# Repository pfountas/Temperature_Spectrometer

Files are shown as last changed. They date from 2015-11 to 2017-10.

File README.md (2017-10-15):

# Temperature Spectrometer
Temperature Spectrometer based on the NXP mbed LPC1768 platform.

This is an embedded digital temperature spectrometer with logging capabilities. The system was based on the NXP mbed LPC1768 platform. The microcontroller used in the temperature logger is based on the 32-bit ARM Cortex-M3 microcontroller with 512 kB flash and 64 kB SRAM. The microcontroller was connected to a TMP102 temperature sensor using an I2C interface and to an LCD screen using an SPI interface. The system supports real-time temperature spectrum computation and control and data export through an on-board USB UART connection.

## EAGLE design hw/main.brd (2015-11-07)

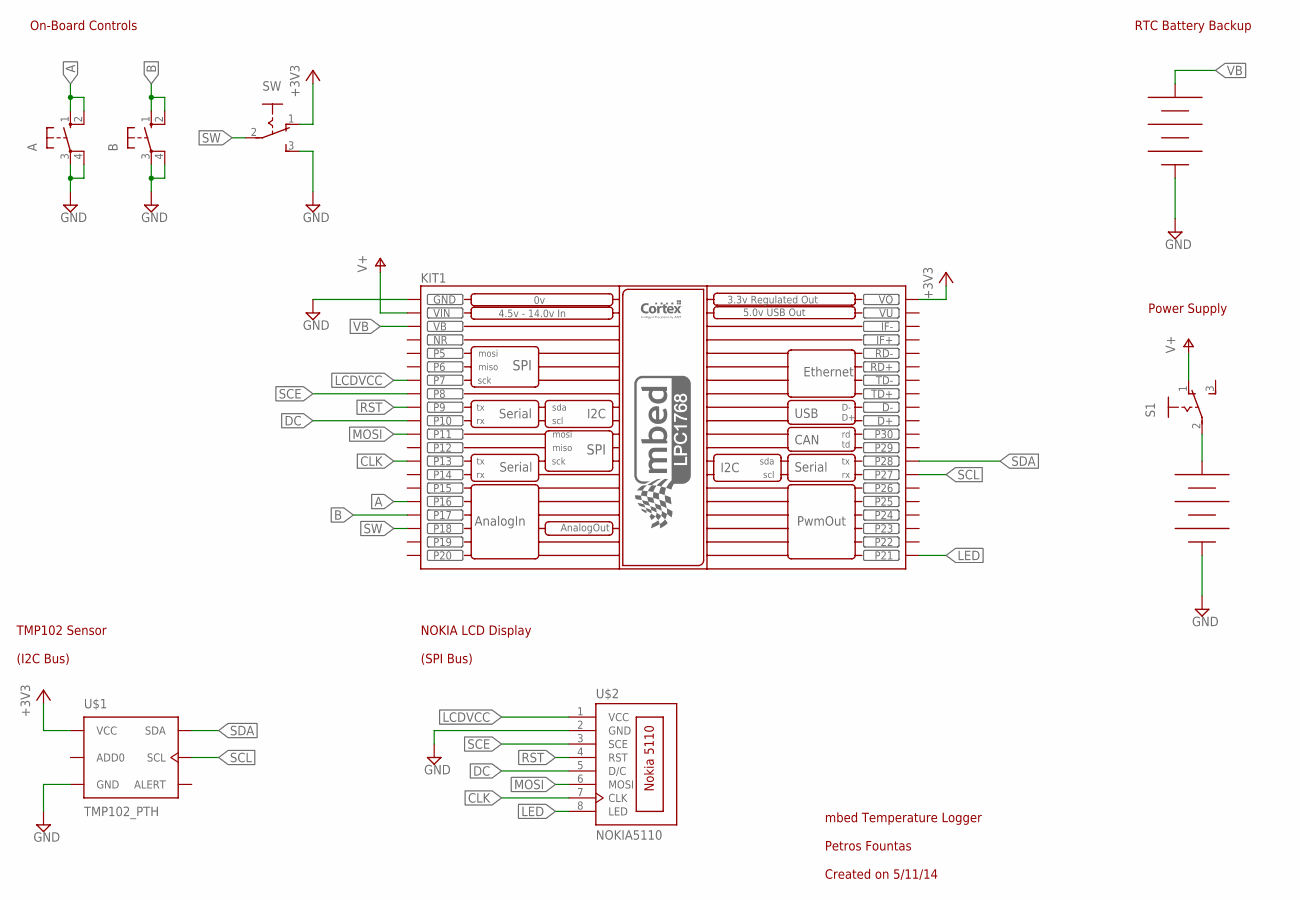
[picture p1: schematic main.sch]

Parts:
A: BUTTON_THT; BUTTON
B: BUTTON_THT; BUTTON
BATT1: BATTERY_4AA
BATT2: BATTERY_H_CR2032; BATTERY_H
KIT1: MBED_SILK; MBED
S1: M251
SW: M251
U$1: TMP102_PTH; TMP102
U$2: NOKIA5110

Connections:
+3V3: KIT1.VOUT (VO), SW.1 (O), U$1.VCC
A: A.1 (S), A.2 (S1), KIT1.P$16 (P16)
B: B.1 (S), B.2 (S1), KIT1.P$17 (P17)
CLK: KIT1.P$13 (P13), U$2.7 (CLK)
DC: KIT1.P$10 (P10), U$2.5 (D/C)
GND: A.3, A.4 (P1), B.3, B.4 (P1), BATT1.-, BATT2.-, KIT1.GND, SW.3 (S), U$1.GND, U$2.2 (GND)
LCDVCC: KIT1.P$7 (P7), U$2.1 (VCC)
LED: KIT1.P$21 (P21), U$2.8 (LED)
MOSI: KIT1.P$11 (P11), U$2.6 (MOSI)
unnamed: BATT1.+, S1.2
NR: KIT1.NR
RST: KIT1.P$9 (P9), U$2.4 (RST)
SCE: KIT1.P$8 (P8), U$2.3 (SCE)
SCL: KIT1.P$27 (P27), U$1.SCL
SDA: KIT1.P$28 (P28), U$1.SDA
SW: KIT1.P$18 (P18), SW.2
V+: KIT1.VIN, S1.1 (O)
VB: BATT2.+, KIT1.VB
VU: KIT1.VU

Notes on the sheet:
mbed Temperature Logger Petros Fountas Created on 5/11/14
RTC Battery Backup
Power Supply
TMP102 Sensor (I2C Bus)
NOKIA LCD Display (SPI Bus)
On-Board Controls

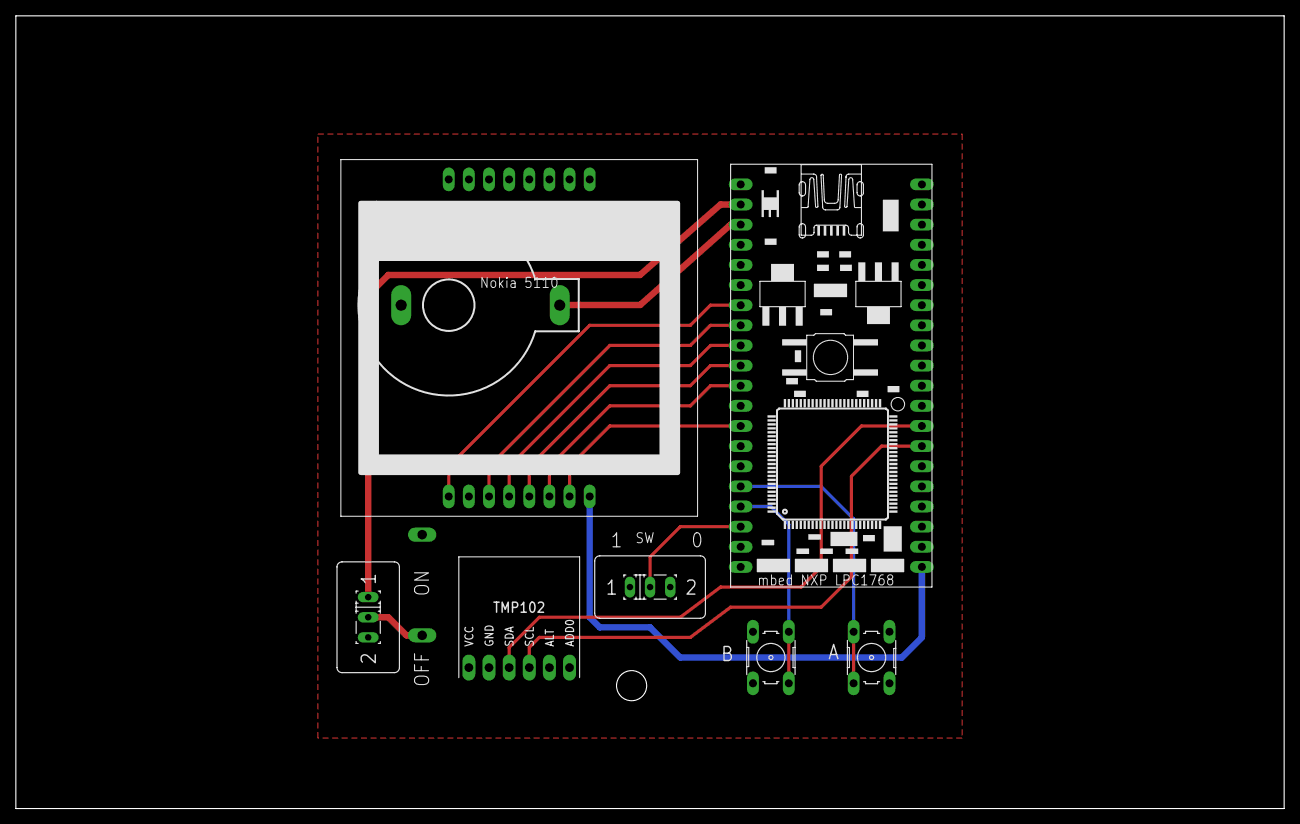
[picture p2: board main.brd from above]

Board: 2 copper layers, 160.0 x 100.0 mm, 9 parts (1 on the bottom side), 17 nets.

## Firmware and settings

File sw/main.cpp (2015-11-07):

#include "mbed.h"
#include "rtos.h"
#include "N5110.h"
#include "TMP102.h"
#include "dsp.h"

// On-boards LEDs for visual feedback
BusOut leds(LED4, LED3, LED2, LED1);

// Local filesystem
LocalFileSystem local("local");
FILE *fp = NULL;

// On-board controls
DigitalIn a_btn(p16, PullUp);
DigitalIn b_btn(p17, PullUp);
DigitalIn sw(p18);

// Serial connection
Serial serial(USBTX, USBRX);
#define getc(c) 	serial.getc(c)
#define printf(...) serial.printf( __VA_ARGS__ )

// Temperature sensor
TMP102 tmp(0x48, p28, p27); // I2C Temperature sensor
bool enable = 0;
bool isLoggingOn = 0;

// LCD display
N5110 display(p7, p8, p9, p10, p11, p13, p21); // LCD 84x48
#define DISP_WIDTH 	84
#define DISP_HEIGHT 48
bool dirty; // screen redraw flag

// DFT
#define N  64 	// samples
#define Fs 1000 // Sampling frequency
float x[N];        // signal
complex_t cx[N];   // complex signal
complex_t X[N];    // DFT
float spectrum[N]; // Spectrum
float Pxx[N];      // PSD

// Control state machine
int state, pstate;
#define DISP_SIG 1
#define DISP_DFT 2
#define DISP_PSD 3

// function to plot line on display
void plotLine(N5110 *display, float points[], int npoints) {

	// find max(point) and min(point)
	float max, min;
	min = max = 0;
	for (int n = 0; n < npoints; n++) {
		max = (points[n] > max) ? points[n] : max;
		min = (points[n] < min) ? points[n] : min;
	}

	// Y-axes
	float zero_point = (0-min)/(max-min); // normalise to [0..1]
	float zero_h = (DISP_HEIGHT-1) - int(zero_point*(DISP_HEIGHT-1)); // px
	display->setPixel(0,zero_h); // set pixel
	display->setPixel(1,zero_h); // set pixel
	for (int h = 0; h < DISP_HEIGHT; h++) {
		display->setPixel(2,h); // set pixel
	}

	// normalise points to screent height
	for (int n = 0; n < npoints; n++) {
		float norm_point = (points[n]-min)/(max-min); // normalise to [0..1]
		float h = (DISP_HEIGHT-1) - int(norm_point*(DISP_HEIGHT-1)); // px
		display->setPixel(n+3,h); // set pixel
	}

	// refresh display
    display->refresh();
}

// Compute DFT
void computeDFT() {

	// convert signal to complex
	for (int n = 0; n < N; n++) cx[n] = complex_num(x[n], 0);

	// init DFT output sequence
	for (int n = 0; n < N; n++) X[n] = complex_num(0, 0); // init to 0

	// compute DFT
	dft(X, cx, N);

	// remove DC component and AC alliases, and spread the rest of the signal
	for (int n = 0; n < N; n++)
		spectrum[n] = 0;
	for (int n = 0; n < floor(N / 2) - 1; n++) {
		spectrum[2 * n] = complex_norm(X[n + 1]);
		spectrum[2 * n + 1] =
				(complex_norm(X[n + 2]) + complex_norm(X[n + 1])) / 2;
	}
}

// Compute PSD
void computePSD() {

	// estimate Power Spectral Density (PSD)
	for (int n = 0; n < N; n++) Pxx[n] = 0; // init to 0
	for (int n = 0; n < floor(N / 2) - 1; n++) {
		Pxx[2 * n] = 20 * log10(pow(complex_norm(X[n + 1]), 2));
		float avg = (complex_norm(X[n + 2]) + complex_norm(X[n + 1])) / 2;
		Pxx[2 * n + 1] = 20 * log10(pow(avg, 2));
	}
}

union sample_union {
	float f;
	unsigned char b[4];
} sample;

// Serial DAQ
void matlab_rx() {

	// get data from Matlab
	for (int n = 0; n < N; n++) {
		x[n] = 0;

		// read number octet by octet
		sample.b[0] = (unsigned char) getc(); // b0
		sample.b[1] = (unsigned char) getc(); // b1
		sample.b[2] = (unsigned char) getc(); // b2
		sample.b[3] = (unsigned char) getc(); // b3

		// save sample
		x[n] = sample.f;
	}

	// DFT
	computeDFT();

	// Periodogram
	computePSD();

	// flag screen to be redraw
	dirty = 1;
}

// Temperature Data-Acquisition thread
void tmp_daq(void const *args) {

	char buffer[30];

	while (1) {
		float avg = 0;

		if (isLoggingOn) {
			// if the file doesn't exist it is created, if it exists, data is appended to the end
			leds = 0xf; // turn on LEDs for feedback
			fp = fopen("/local/log.csv", "a"); // open 'log.csv' for appending
		} else {
			fclose(fp); // close file
			leds = 0x0; // turn off LEDs to signify file access has finished
		}

		// acquire enough samples for the DFT
		for (int n = 0; n < N; n++) {
			float temp = 0;
			// get temperature
			tmp.temp(&temp);
			avg += (x[n] = temp);

			// format time into a string (time and date)
			time_t seconds = time(NULL); // get current time
			strftime(buffer, 30, "%X %D", localtime(&seconds));
			if (isLoggingOn && fp != NULL) {
				// write to local filesystem
				fprintf(fp, "%s, %.2f\n", buffer, temp);
			}

			// 8Hz daq rate (maximum)
			Thread::wait(0.125);

			//wait(60);
		}
		avg /= N;
		// write to serial
		//printf("%s, %.2f\n", buffer, temp);

		// display average temperature
		//char buffer[6] = "";
		//sscanf(buffer,"%f",&avg);
		//display.printString(buffer,65,0);

		// DFT
		computeDFT();

		// Periodogram
		computePSD();

		// flag screen to be redraw
		dirty = 1;
	}
}

// main
int main() {

	set_time(1420753443); // initialise time to 1st January 1970

	// init temperature sensor
	enable = 0;
	tmp.init(1);

	// init LCD display
	dirty = 0;
	display.init();

	// temperature daq thread
	Thread thread(tmp_daq);

	// matlab rx callback
	serial.attach(&matlab_rx);

	// Controller
	pstate = 0,state = DISP_SIG; // init control state machine
	while(1) {

		// Controls
		if (sw) { // SW = 1 - Signal Analysis ...
			if (!a_btn) // Button A - Spectrum display
				state = DISP_DFT;
			if (!b_btn) // Button B - Power Spectral Density display
				state = DISP_PSD;
		} else { // SW = 0 - Temperature display, Logging control ...
			state = DISP_SIG;
			if (!a_btn)  // Button A - Switch logging On (default is Off)
				isLoggingOn = 1;
			if (!b_btn) // Button B - Switch logging Off
				isLoggingOn = 0;
		}

		// State decoder
		char phrase[13];
		if (dirty || pstate != state) {
			display.clear(); // clear display

			switch (state) {
			case DISP_SIG:
				sprintf(phrase,"Temp: %.2f C",x[0]);
				display.printString(phrase,0,0); // print temperature
				break;
			case DISP_DFT:
				plotLine(&display,spectrum,N); // Display Spectrum
				break;
			case DISP_PSD:
				plotLine(&display,Pxx,N); // Display Periodogram
				break;
			default:
				sprintf(phrase,"Temp: %.2f C",x[0]);
				display.printString(phrase,0,0); // print temperature
				break;
			}
			dirty = 0;
			pstate = state;
		}

	}

}

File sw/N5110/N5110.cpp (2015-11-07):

/**
@file N5110.cpp

@brief Member functions implementations

*/
#include "mbed.h"
#include "N5110.h"


N5110::N5110(PinName pwrPin, PinName scePin, PinName rstPin, PinName dcPin, PinName mosiPin, PinName sclkPin, PinName ledPin)
{
    
    spi = new SPI(mosiPin,NC,sclkPin); // create new SPI instance and initialise
    initSPI();    
    
    // set up pins as required
    led = new PwmOut(ledPin);
    pwr = new DigitalOut(pwrPin);
    sce = new DigitalOut(scePin);
    rst = new DigitalOut(rstPin);
    dc = new DigitalOut(dcPin);

}

// initialise function - powers up and sends the initialisation commands
void N5110::init()
{
    turnOn();     // power up
    wait_ms(10);  // small delay seems to prevent spurious pixels during mbed reset
    reset();      // reset LCD - must be done within 100 ms

    // function set - extended
    sendCommand(0x20 | CMD_FS_ACTIVE_MODE | CMD_FS_HORIZONTAL_MODE | CMD_FS_EXTENDED_MODE);
    // Don't completely understand these parameters - they seem to work as they are
    // Consult the datasheet if you need to change them
    sendCommand(CMD_VOP_7V38);    // operating voltage - these values are from Chris Yan's Library
    sendCommand(CMD_TC_TEMP_2);   // temperature control
    sendCommand(CMD_BI_MUX_48);   // bias

    // function set - basic
    sendCommand(0x20 | CMD_FS_ACTIVE_MODE | CMD_FS_HORIZONTAL_MODE | CMD_FS_BASIC_MODE);
    normalMode();  // normal video mode by default
    sendCommand(CMD_DC_NORMAL_MODE);  // black on white

    // RAM is undefined at power-up so clear
    clearRAM();

}
 
// sets normal video mode (black on white) 
void N5110::normalMode() {
     sendCommand(CMD_DC_NORMAL_MODE);  
   
}

// sets normal video mode (white on black) 
void N5110::inverseMode() {
    sendCommand(CMD_DC_INVERT_VIDEO); 
}

// function to power up the LCD and backlight
void N5110::turnOn()
{
    // set brightness of LED - 0.0 to 1.0 - default is 50%
    setBrightness(0.5);
    pwr->write(1);  // apply power
}

// function to power down LCD
void N5110::turnOff()
{
    setBrightness(0.0);  // turn backlight off
    clearRAM();   // clear RAM to ensure specified current consumption
    // send command to ensure we are in basic mode
    sendCommand(0x20 | CMD_FS_ACTIVE_MODE | CMD_FS_HORIZONTAL_MODE | CMD_FS_BASIC_MODE);
    // clear the display
    sendCommand(CMD_DC_CLEAR_DISPLAY);
    // enter the extended mode and power down
    sendCommand(0x20 | CMD_FS_POWER_DOWN_MODE | CMD_FS_HORIZONTAL_MODE | CMD_FS_EXTENDED_MODE);
    // small delay and then turn off the power pin
    wait_ms(10);
    pwr->write(0);

}

// function to change LED backlight brightness
void N5110::setBrightness(float brightness)
{
    // check whether brightness is within range
    if (brightness < 0.0)
        brightness = 0.0;
    if (brightness > 1.0)
        brightness = 1.0;
    // set PWM duty cycle
    led->write(brightness);
}


// pulse the active low reset line
void N5110::reset()
{
    rst->write(0);  // reset the LCD
    rst->write(1);
}

// function to initialise SPI peripheral
void N5110::initSPI()
{
    spi->format(8,1);    // 8 bits, Mode 1 - polarity 0, phase 1 - base value of clock is 0, data captured on falling edge/propagated on rising edge
    spi->frequency(4000000);  // maximum of screen is 4 MHz
}

// send a command to the display
void N5110::sendCommand(unsigned char command)
{
    dc->write(0);  // set DC low for command
    sce->write(0); // set CE low to begin frame
    spi->write(command);  // send command
    dc->write(1);  // turn back to data by default
    sce->write(1); // set CE high to end frame (expected for transmission of single byte)

}

// send data to the display at the current XY address
// dc is set to 1 (i.e. data) after sending a command and so should
// be the default mode.
void N5110::sendData(unsigned char data)
{
    sce->write(0);   // set CE low to begin frame
    spi->write(data);
    sce->write(1);  // set CE high to end frame (expected for transmission of single byte)
}

// this function writes 0 to the 504 bytes to clear the RAM
void N5110::clearRAM()
{
    int i;
    sce->write(0);  //set CE low to begin frame
    for(i = 0; i < 504; i++) { // 48 x 84 bits = 504 bytes
        spi->write(0x00);  // send 0's
    }
    sce->write(1); // set CE high to end frame

}

// function to set the XY address in RAM for subsequenct data write 
void N5110::setXYAddress(int x, int y)
{
    // check whether address is in range
    if (x > 83)
        x=83;
    if (y > 5)
        y=5;
    if (x < 0)
        x=0;
    if (y < 0)
        y=0;

    sendCommand(0x80 | x);  // send addresses to display with relevant mask
    sendCommand(0x40 | y);
}

// These functions are used to set, clear and get the value of pixels in the display
// Pixels are addressed in the range of 0 to 47 (y) and 0 to 83 (x).  The refresh()
// function must be called after set and clear in order to update the display
void N5110::setPixel(int x, int y)
{
    // calculate bank and shift 1 to required position in the data byte
    buffer[x][y/8] |= (1 << y%8);
}

void N5110::clearPixel(int x, int y)
{
    // calculate bank and shift 1 to required position (using bit clear)
    buffer[x][y/8] &= ~(1 << y%8);
}

int N5110::getPixel(int x, int y)
{
    // return relevant bank and mask required bit
    return (int) buffer[x][y/8] & (1 << y%8);

}

// function to refresh the display
void N5110::refresh()
{
    int i,j;
    
    setXYAddress(0,0);  // important to set address back to 0,0 before refreshing display
    // address auto increments after printing string, so buffer[0][0] will not coincide
    // with top-left pixel after priting string
    
    sce->write(0);  //set CE low to begin frame

    for(j = 0; j < 6; j++) {  // be careful to use correct order (j,i) for horizontal addressing
        for(i = 0; i < 84; i++) {
            spi->write(buffer[i][j]);  // send buffer
        }
    }
    sce->write(1); // set CE high to end frame

}

// fills the buffer with random bytes.  Can be used to test the display.
// The rand() function isn't seeded so it probably creates the same pattern everytime
void N5110::randomiseBuffer()
{
    int i,j;
    for(j = 0; j < 6; j++) {  // be careful to use correct order (j,i) for horizontal addressing
        for(i = 0; i < 84; i++) {
            buffer[i][j] = rand()%256;  // generate random byte
        }
    }

}

// function to print 5x7 font
void N5110::printChar(char c)
{
    int i;
    // loop through 5 columns
    for (i = 0; i < 5 ; i++ ) {
        sendData(font5x7[(c - 32)*5 + i]);
        // array is offset by 32 relative to ASCII, each character is 5 pixels wide
        // the X address is automatically incremented after each data write
    }
    sendData(0); // send an empty byte to introduce space between characters

}
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
